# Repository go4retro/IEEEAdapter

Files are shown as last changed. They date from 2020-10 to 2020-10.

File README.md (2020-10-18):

# IEEE Adapter
PET/CBM IEEE edge connector to Centronics 24 adapter

## Introduction

Most likely (though I cannot confirm) the cost of placing a Centronics 24 connector on the PET 2001 motherboard and the unknown adoption of IEEE devices led Commodore to skip the connector and simply bring all signals needed to a .156" 12/24 pin male edge connector on the back of the unit.  Since the peripherals included the proper connector, Commodore then sold a special cable that contained the proper connector on one end and an female edge connector on the other end. PET/CBM owners would then need 1 of these cables at the start of the IEEE chain. Since reproducing this cable is cost prohibitive, this device economically converts from the .156" 12/24 connector the the Centronics-24 connector. The device is strictly passive, though the IFC signals can be switched or jumpered if desired.

## Purchase

The finished unit is available for purchase from [RETRO Innovations](http://store.go4retro.com/ieee-cable-adapter/).

## License

Copyright (C) 2012-20  RETRO Innovations

These files are free designs; you can redistribute them and/or modify
them under the terms of the Creative Commons Attribution-ShareAlike 
4.0 International License.

You should have received a copy of the license along with this
work. If not, see <http://creativecommons.org/licenses/by-sa/4.0/>.

These files are distributed in the hope that they will be useful,
but WITHOUT ANY WARRANTY; without even the implied warranty of
MERCHANTABILITY or FITNESS FOR A PARTICULAR PURPOSE.  See the
license for more details.

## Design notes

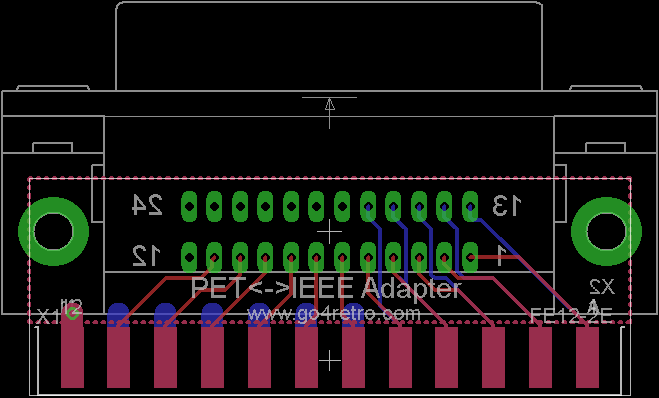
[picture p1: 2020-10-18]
pcb/IEEEAdapter_v1.png

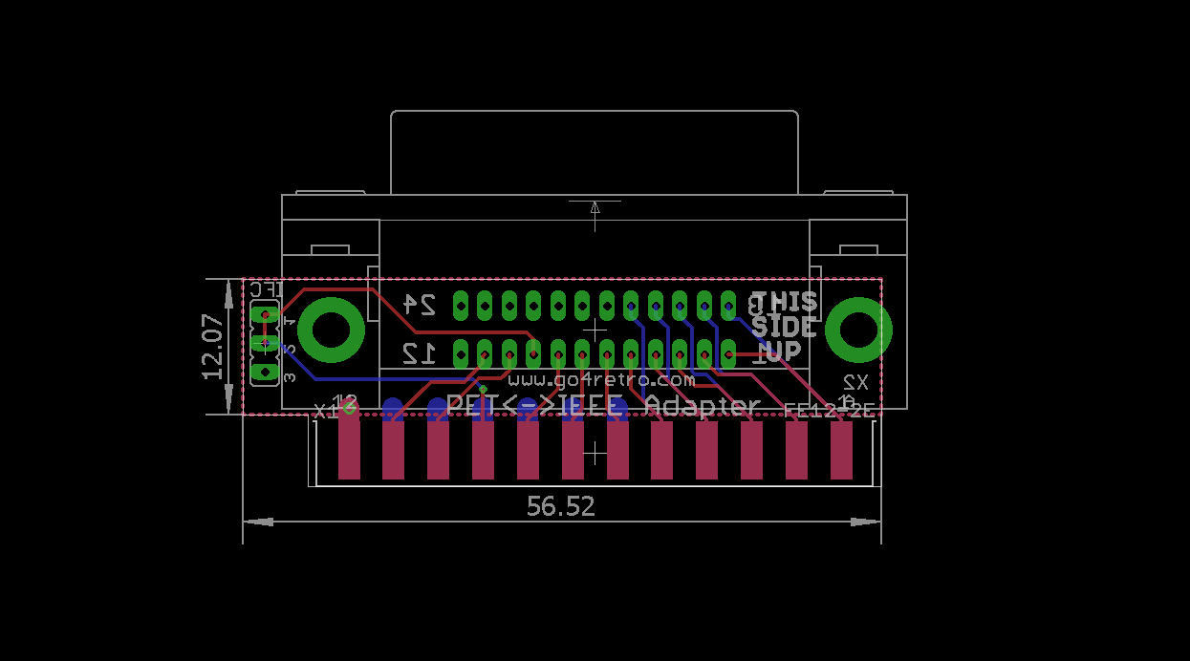
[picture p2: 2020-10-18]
pcb/IEEEAdapter_v2.png

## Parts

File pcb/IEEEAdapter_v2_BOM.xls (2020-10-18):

ID | Part Number | Description | Supplier | Quantity
X1 | KE-DXE-24-LF | 12/24 .156" edge connector | customer | 1
X2 | RR2-24 | Centronics 24 socket | customer | 1
IFC | 1x3 header | 1x3 header |  | 1
jumper | jumper | jumper (goes on pins 1 and 2 |  | 1

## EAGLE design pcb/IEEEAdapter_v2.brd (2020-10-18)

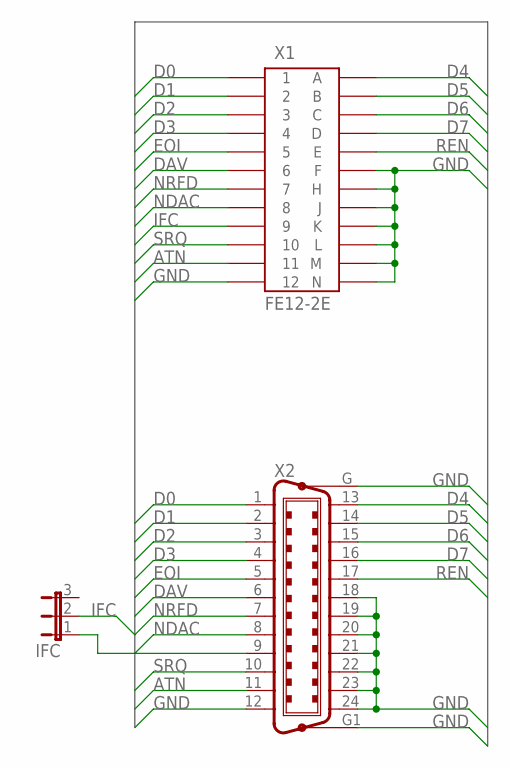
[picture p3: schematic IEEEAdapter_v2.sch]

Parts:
IFC: JP2E; JP2
X1: FE12-2E; FE12-2_SHORT
X2: C24HP; 24HP

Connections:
ATN: X1.11, X2.11
D0: X1.1, X2.1
D1: X1.2, X2.2
D2: X1.3, X2.3
D3: X1.4, X2.4
D4: X1.A, X2.13
D5: X1.B, X2.14
D6: X1.C, X2.15
D7: X1.D, X2.16
DAV: X1.6, X2.6
EOI: X1.5, X2.5
GND: X1.12, X1.F, X1.H, X1.J, X1.K, X1.L, X1.M, X1.N, X2.12, X2.18, X2.19, X2.20, X2.21, X2.22, X2.23, X2.24, X2.G, X2.G1
IFC: IFC.2, X1.9
unnamed: IFC.1, X2.9
NDAC: X1.8, X2.8
NRFD: X1.7, X2.7
REN: X1.E, X2.17
SRQ: X1.10, X2.10

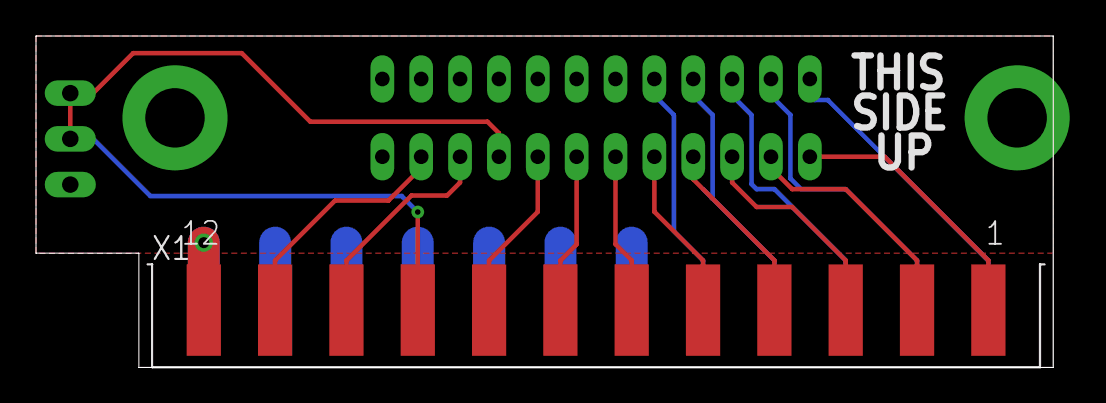
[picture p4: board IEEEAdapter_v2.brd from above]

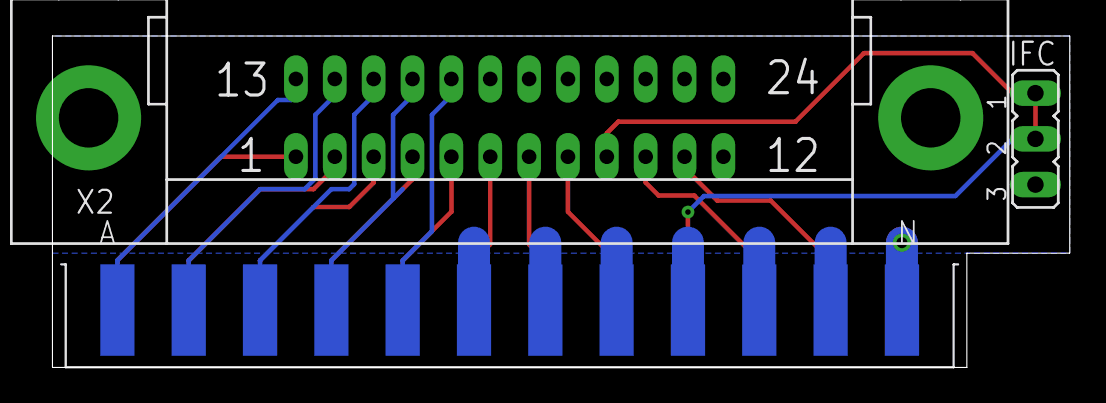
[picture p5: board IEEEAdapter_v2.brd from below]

Board: 2 copper layers, 56.5 x 18.4 mm, 3 parts (2 on the bottom side), 18 nets.

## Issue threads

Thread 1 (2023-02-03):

V2 Board

number-g, 2023-02-03:
Hi,

What is the IFC jumper for on the V2 board?

Thanks

go4retro, 2023-04-25:
Folks were interested in disconnecting that line, to allow the PET to be reset without affecting current drive state.

Closed 2023-04-25.
